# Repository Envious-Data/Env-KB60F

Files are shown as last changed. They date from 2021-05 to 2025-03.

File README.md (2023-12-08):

# Env-KB60F
 Another Custom Mechanical Keyboard... F stands for FOREHEAD!

 Project Name: KB60F
 Nickname: Lil Delirium

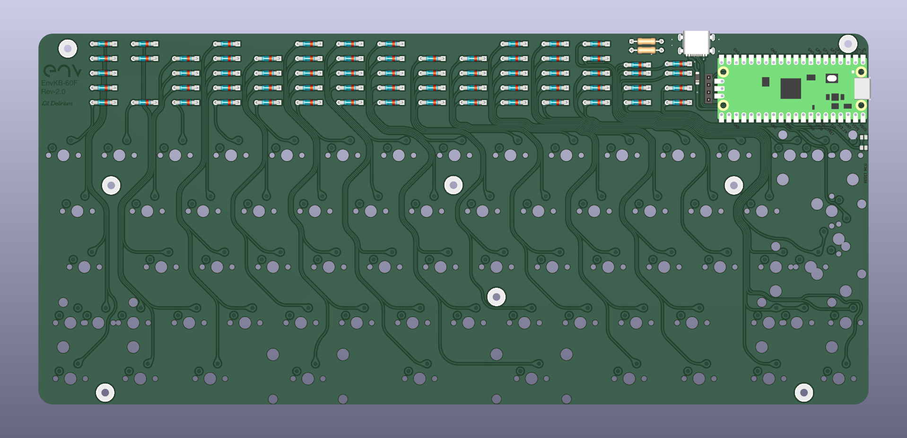
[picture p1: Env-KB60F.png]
PCBShot


### About!
This is a simple-ish 60% design using a Raspberry Pi Pico. Its a standard 60% layout supporting ANSI and ISO.
Optionally if you have your own PCBs made you can use some pogo pins with a 1mm post to connect the TP pads on the underside of a raspberry pi pico, This will allow functionality of the USB type-c port if populated.

there are some spare GPIOs and a space for a header (mainly for a small oled) so feel free to add things if you can, I always enjoy seeing people using my keyboards for things I never thought of or intended.

### DETAILS
This keyboard has been merged into QMK so you can either compile it from the QMK code or download the pre-built firmware
https://github.com/qmk/qmk_firmware/tree/master/keyboards/enviousdesign/60f

https://github.com/Envious-Data/EnvKB-QMK/tree/main/_PREBUILTFIRMWARES

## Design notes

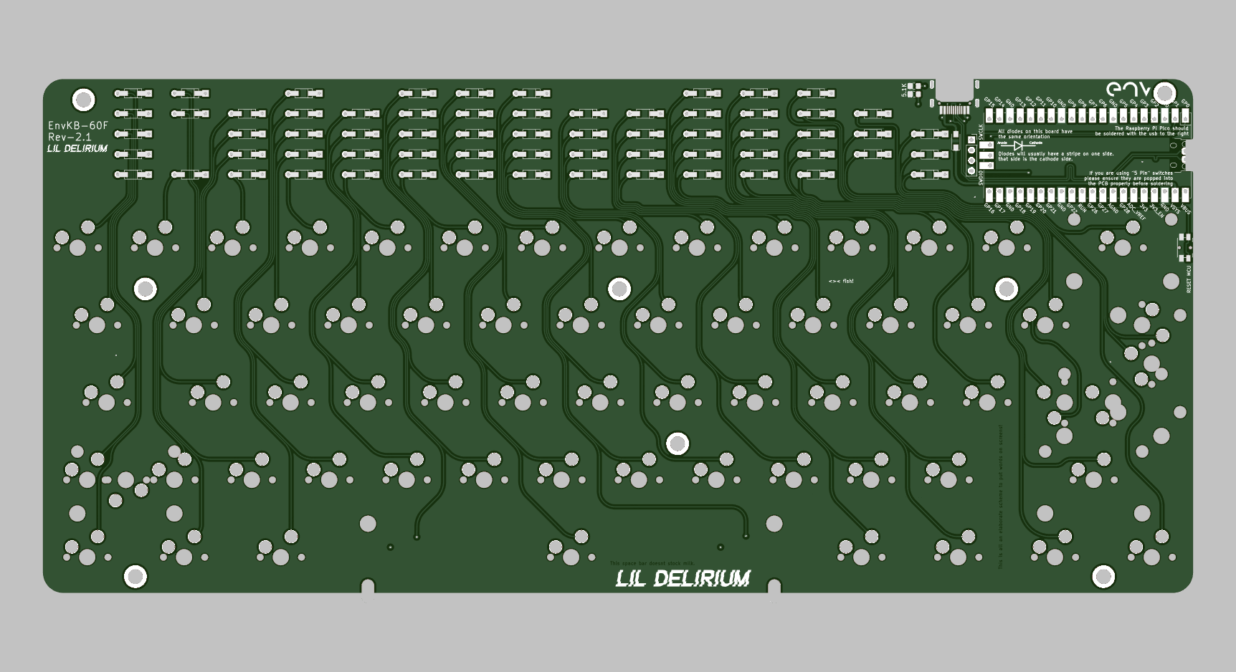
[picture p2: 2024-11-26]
KiCad Files/MainPCB_MX_HS/Env-KB60MXHS.png

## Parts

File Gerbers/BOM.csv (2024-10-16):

Designator | Footprint | Quantity | Value | LCSC Part #
5.1K1, 5.1K2 | 0805 | 2 | 5.1K 0805 Resistor
D_1, D_10, D_11, D_12, D_13, D_14, D_15, D_16, D_17, D_18, D_19, D_2, D_20, D_21, D_22, D_23, D_24, D_25, D_26, D_27, D_28, D_29, D_3, D_30, D_31, D_32, D_33, D_34, D_35, D_36, D_37, D_38, D_39, D_4, D_40, D_41, D_42, D_43, D_44, D_45, D_46, D_47, D_48, D_49, D_5, D_50, D_51, D_52, D_53, D_54, D_55, D_56, D_57, D_58, D_59, D_590, D_591, D_6, D_60, D_61, D_62, D_63, D_7, D_8, D_9 | SOD-123+D_DO-35_SOD27_P7.62mm_Horizontal | 65 | LL4148
D_64 | D_SOD-123 | 1 | 1n5817W
H1, H10, H11, H2, H3, H4, H6, H9 | MountingHole_2.2mm_M2-MODIFIED | 8 | SMTSO2035CTJ
J1 | PinSocket_1x04_P2.54mm_Vertical | 1 | Conn_01x04
K_1, K_10, K_11, K_12, K_13, K_14, K_15, K_16, K_17, K_18, K_19, K_2, K_20, K_21, K_22, K_23, K_24, K_25, K_26, K_27, K_28, K_29, K_3, K_30, K_31, K_32, K_33, K_34, K_35, K_36, K_37, K_38, K_39, K_4, K_40, K_41, K_42, K_43, K_44, K_45, K_46, K_47, K_48, K_49, K_5, K_50, K_51, K_52, K_53, K_54, K_55, K_56, K_57, K_58, K_59, K_6, K_60, K_61, K_62, K_63, K_64, K_65, K_7, K_8, K_9 | MXOnly-1U-Hotswap-Modified | 65 | CPG151101S11
SW1 | Panasonic_EVQPUL_EVQPUC | 1 | EVQPUL
U1 | RPi_Pico_SMD_TH_MODIFIED | 1 | Pico
USB1 | USB_C_TYPE-C-31-M-14 | 1 | TYPE-C-31-M-14 | C319148

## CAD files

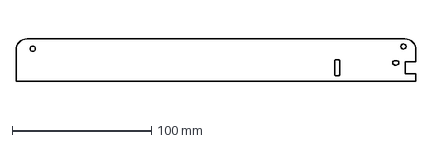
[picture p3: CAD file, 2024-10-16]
KiCad Files/KB60F - Top Cover Acrylic updated.dxf
287.1 x 30.4 mm

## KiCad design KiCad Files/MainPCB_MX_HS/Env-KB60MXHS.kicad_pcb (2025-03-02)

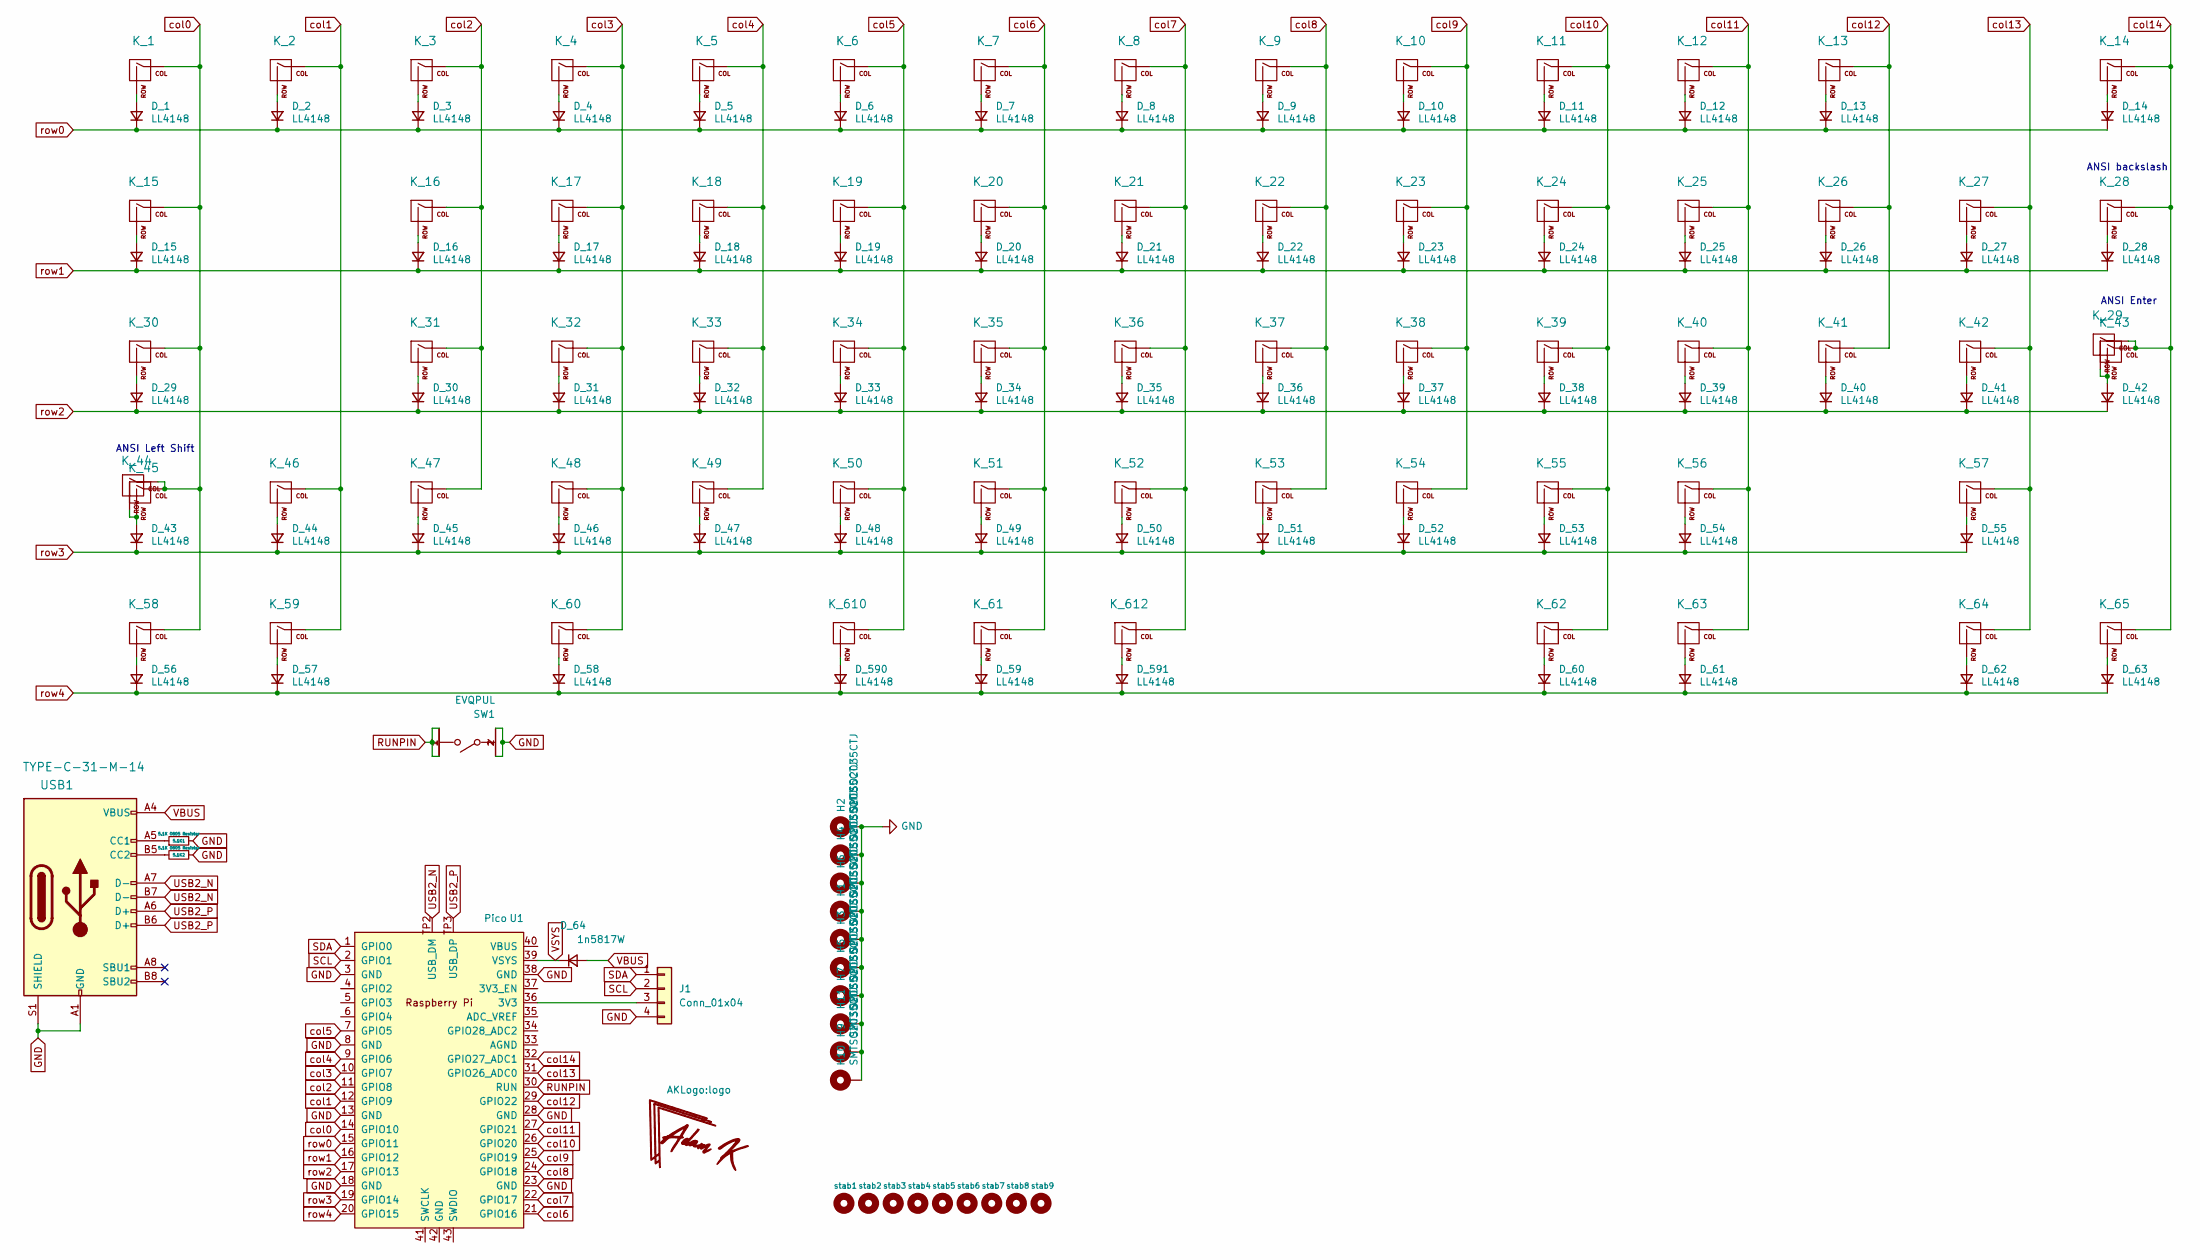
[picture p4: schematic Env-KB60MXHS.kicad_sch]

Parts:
5.1K1, 5.1K2: 5.1K 0805 Resistor; R_0805_2012Metric_Pad1.20x1.40mm_HandSolder
D_1, D_2, D_3, D_4, D_5, D_6, D_7, D_8, D_9, D_10, D_11, D_12, D_13, D_14, D_15, D_16, D_17, D_18, D_19, D_20, D_21, D_22, D_23, D_24, D_25, D_26, D_27, D_28, D_29, D_30, D_31, D_32, D_33, D_34, D_35, D_36, D_37, D_38, D_39, D_40, D_41, D_42, D_43, D_44, D_45, D_46, D_47, D_48, D_49, D_50, D_51, D_52, D_53, D_54, D_55, D_56, D_57, D_58, D_59, D_60, D_61, D_62, D_63, D_590, D_591: LL4148; SOD-123+D_DO-35_SOD27_P7.62mm_Horizontal
D_64: 1n5817W; D_SOD-123
H1, H2, H3, H4, H5, H6, H7, H9, H10, H11: SMTSO2035CTJ; MountingHole_2.2mm_M2-MODIFIED
J1: Conn_01x04; PinSocket_1x04_P2.54mm_Vertical
K_1, K_2, K_3, K_4, K_5, K_6, K_7, K_8, K_9, K_10, K_11, K_12, K_13, K_14, K_15, K_16, K_17, K_18, K_19, K_20, K_21, K_22, K_23, K_24, K_25, K_26, K_27, K_28, K_29, K_30, K_31, K_32, K_33, K_34, K_35, K_36, K_37, K_38, K_39, K_40, K_41, K_42, K_43, K_44, K_45, K_46, K_47, K_48, K_49, K_50, K_51, K_52, K_53, K_54, K_55, K_56, K_57, K_58, K_59, K_60, K_61, K_62, K_63, K_64, K_65, K_610, K_612: CPG151101S11; MXOnly-1U-Hotswap-Modified
SW1: EVQPUL; Panasonic_EVQPUL_EVQPUC
U1: Pico; RPi_Pico_SMD_TH_MODIFIED
USB1: TYPE-C-31-M-14; USB_C_TYPE-C-31-M-14; MPN U262-161N-4BVC11; LCSC C319148
stab1, stab2, stab3, stab4, stab5, stab6, stab7, stab8: MX Stabilizer; Stabilizer_Cherry_MX_2u
stab9: MX Stabilizer; Stabilizer_Cherry_MX_6.25u

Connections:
GND: 5.1K1.2, 5.1K2.1, J1.4, SW1.2, SW1.2', U1.3 (GND), U1.8 (GND), U1.13 (GND), U1.18 (GND), U1.23 (GND), U1.28 (GND), U1.38 (GND), USB1.A1 (GND), USB1.A12 (GND), USB1.B1 (GND), USB1.B12 (GND), USB1.S1 (SHIELD)
unnamed: D_1.2 (A), K_1.2 (ROW)
unnamed: D_2.2 (A), K_2.2 (ROW)
unnamed: D_3.2 (A), K_3.2 (ROW)
unnamed: D_4.2 (A), K_4.2 (ROW)
unnamed: D_5.2 (A), K_5.2 (ROW)
unnamed: D_6.2 (A), K_6.2 (ROW)
unnamed: D_7.2 (A), K_7.2 (ROW)
unnamed: D_8.2 (A), K_8.2 (ROW)
unnamed: D_9.2 (A), K_9.2 (ROW)
unnamed: D_10.2 (A), K_10.2 (ROW)
unnamed: D_11.2 (A), K_11.2 (ROW)
unnamed: D_12.2 (A), K_12.2 (ROW)
unnamed: D_13.2 (A), K_13.2 (ROW)
unnamed: D_14.2 (A), K_14.2 (ROW)
unnamed: D_15.2 (A), K_15.2 (ROW)
unnamed: D_16.2 (A), K_16.2 (ROW)
unnamed: D_17.2 (A), K_17.2 (ROW)
unnamed: D_18.2 (A), K_18.2 (ROW)
unnamed: D_19.2 (A), K_19.2 (ROW)
unnamed: D_20.2 (A), K_20.2 (ROW)
unnamed: D_21.2 (A), K_21.2 (ROW)
unnamed: D_22.2 (A), K_22.2 (ROW)
unnamed: D_23.2 (A), K_23.2 (ROW)
unnamed: D_24.2 (A), K_24.2 (ROW)
unnamed: D_25.2 (A), K_25.2 (ROW)
unnamed: D_26.2 (A), K_26.2 (ROW)
unnamed: D_27.2 (A), K_27.2 (ROW)
unnamed: D_28.2 (A), K_28.2 (ROW)
unnamed: D_29.2 (A), K_30.2 (ROW)
unnamed: D_30.2 (A), K_31.2 (ROW)
unnamed: D_31.2 (A), K_32.2 (ROW)
unnamed: D_32.2 (A), K_33.2 (ROW)
unnamed: D_33.2 (A), K_34.2 (ROW)
unnamed: D_34.2 (A), K_35.2 (ROW)
unnamed: D_35.2 (A), K_36.2 (ROW)
unnamed: D_36.2 (A), K_37.2 (ROW)
unnamed: D_37.2 (A), K_38.2 (ROW)
unnamed: D_38.2 (A), K_39.2 (ROW)
unnamed: D_39.2 (A), K_40.2 (ROW)
unnamed: D_40.2 (A), K_41.2 (ROW)
unnamed: D_41.2 (A), K_42.2 (ROW)
unnamed: D_42.2 (A), K_29.2 (ROW), K_43.2 (ROW)
unnamed: D_43.2 (A), K_44.2 (ROW), K_45.2 (ROW)
unnamed: D_44.2 (A), K_46.2 (ROW)
unnamed: D_45.2 (A), K_47.2 (ROW)
unnamed: D_46.2 (A), K_48.2 (ROW)
unnamed: D_47.2 (A), K_49.2 (ROW)
unnamed: D_48.2 (A), K_50.2 (ROW)
unnamed: D_49.2 (A), K_51.2 (ROW)
unnamed: D_50.2 (A), K_52.2 (ROW)
unnamed: D_51.2 (A), K_53.2 (ROW)
unnamed: D_52.2 (A), K_54.2 (ROW)
unnamed: D_53.2 (A), K_55.2 (ROW)
unnamed: D_54.2 (A), K_56.2 (ROW)
unnamed: D_55.2 (A), K_57.2 (ROW)
unnamed: D_56.2 (A), K_58.2 (ROW)
unnamed: D_57.2 (A), K_59.2 (ROW)
unnamed: D_58.2 (A), K_60.2 (ROW)
unnamed: D_59.2 (A), K_61.2 (ROW)
unnamed: D_60.2 (A), K_62.2 (ROW)
unnamed: D_61.2 (A), K_63.2 (ROW)
unnamed: D_62.2 (A), K_64.2 (ROW)
unnamed: D_63.2 (A), K_65.2 (ROW)
unnamed: D_590.2 (A), K_610.2 (ROW)
unnamed: D_591.2 (A), K_612.2 (ROW)
unnamed: H1.1, H2.1, H3.1, H4.1, H5.1, H6.1, H7.1, H9.1, H10.1, H11.1
unnamed: J1.3, U1.36 (3V3)
unnamed: 5.1K1.1, USB1.A5 (CC1)
unnamed: 5.1K2.2, USB1.B5 (CC2)
RUNPIN: SW1.1, SW1.1', U1.30 (RUN)
SCL: J1.2, U1.2 (GPIO1)
SDA: J1.1, U1.1 (GPIO0)
USB2_N: U1.TP2 (USB_DM), USB1.A7 (D-), USB1.B7 (D-)
USB2_P: U1.TP3 (USB_DP), USB1.A6 (D+), USB1.B6 (D+)
VBUS: D_64.2 (A), USB1.A4 (VBUS), USB1.A9 (VBUS), USB1.B4 (VBUS), USB1.B9 (VBUS)
VSYS: D_64.1 (K), U1.39 (VSYS)
col0: K_1.1 (COL), K_15.1 (COL), K_30.1 (COL), K_44.1 (COL), K_45.1 (COL), K_58.1 (COL), U1.14 (GPIO10)
col1: K_2.1 (COL), K_46.1 (COL), K_59.1 (COL), U1.12 (GPIO9)
col2: K_3.1 (COL), K_16.1 (COL), K_31.1 (COL), K_47.1 (COL), U1.11 (GPIO8)
col3: K_4.1 (COL), K_17.1 (COL), K_32.1 (COL), K_48.1 (COL), K_60.1 (COL), U1.10 (GPIO7)
col4: K_5.1 (COL), K_18.1 (COL), K_33.1 (COL), K_49.1 (COL), U1.9 (GPIO6)
col5: K_6.1 (COL), K_19.1 (COL), K_34.1 (COL), K_50.1 (COL), K_610.1 (COL), U1.7 (GPIO5)
col6: K_7.1 (COL), K_20.1 (COL), K_35.1 (COL), K_51.1 (COL), K_61.1 (COL), U1.21 (GPIO16)
col7: K_8.1 (COL), K_21.1 (COL), K_36.1 (COL), K_52.1 (COL), K_612.1 (COL), U1.22 (GPIO17)
col8: K_9.1 (COL), K_22.1 (COL), K_37.1 (COL), K_53.1 (COL), U1.24 (GPIO18)
col9: K_10.1 (COL), K_23.1 (COL), K_38.1 (COL), K_54.1 (COL), U1.25 (GPIO19)
col10: K_11.1 (COL), K_24.1 (COL), K_39.1 (COL), K_55.1 (COL), K_62.1 (COL), U1.26 (GPIO20)
col11: K_12.1 (COL), K_25.1 (COL), K_40.1 (COL), K_56.1 (COL), K_63.1 (COL), U1.27 (GPIO21)
col12: K_13.1 (COL), K_26.1 (COL), K_41.1 (COL), U1.29 (GPIO22)
col13: K_27.1 (COL), K_42.1 (COL), K_57.1 (COL), K_64.1 (COL), U1.31 (GPIO26_ADC0)
col14: K_14.1 (COL), K_28.1 (COL), K_29.1 (COL), K_43.1 (COL), K_65.1 (COL), U1.32 (GPIO27_ADC1)
row0: D_1.1 (K), D_2.1 (K), D_3.1 (K), D_4.1 (K), D_5.1 (K), D_6.1 (K), D_7.1 (K), D_8.1 (K), D_9.1 (K), D_10.1 (K), D_11.1 (K), D_12.1 (K), D_13.1 (K), D_14.1 (K), U1.15 (GPIO11)
row1: D_15.1 (K), D_16.1 (K), D_17.1 (K), D_18.1 (K), D_19.1 (K), D_20.1 (K), D_21.1 (K), D_22.1 (K), D_23.1 (K), D_24.1 (K), D_25.1 (K), D_26.1 (K), D_27.1 (K), D_28.1 (K), U1.16 (GPIO12)
row2: D_29.1 (K), D_30.1 (K), D_31.1 (K), D_32.1 (K), D_33.1 (K), D_34.1 (K), D_35.1 (K), D_36.1 (K), D_37.1 (K), D_38.1 (K), D_39.1 (K), D_40.1 (K), D_41.1 (K), D_42.1 (K), U1.17 (GPIO13)
row3: D_43.1 (K), D_44.1 (K), D_45.1 (K), D_46.1 (K), D_47.1 (K), D_48.1 (K), D_49.1 (K), D_50.1 (K), D_51.1 (K), D_52.1 (K), D_53.1 (K), D_54.1 (K), D_55.1 (K), U1.19 (GPIO14)
row4: D_56.1 (K), D_57.1 (K), D_58.1 (K), D_59.1 (K), D_60.1 (K), D_61.1 (K), D_62.1 (K), D_63.1 (K), D_590.1 (K), D_591.1 (K), U1.20 (GPIO15)

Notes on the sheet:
ANSI Left Shift
ANSI backslash
ANSI Enter

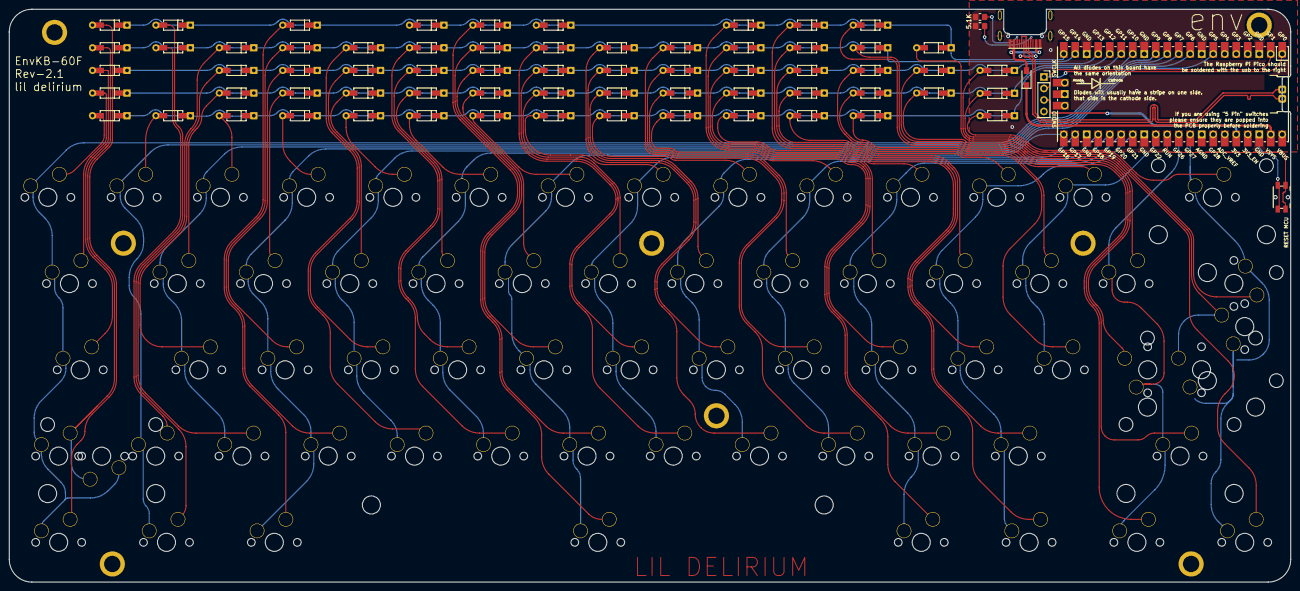
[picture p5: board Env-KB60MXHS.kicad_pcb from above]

Board: 2 copper layers, 283.0 x 126.5 mm, 151 parts (0 on the bottom side), 94 nets.

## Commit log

2021-04-23 Added Files n whatnot
    [Env-KB60F.kicad_pcb, Env-KB60F.sch]
2021-04-23 Aligned diodes as preferred
    [Env-KB60F.kicad_pcb]
2021-04-23 Diodes were wrong direction
    [Env-KB60F.kicad_pcb, Env-KB60F.sch]
2021-04-23 Added More traces n stuff
    [Env-KB60F.kicad_pcb]
2021-04-23 General Re-doing of stuff
    [Env-KB60F.kicad_pcb, Env-KB60F.sch]
2021-04-24 Added some mount holes n stuff
    [Env-KB60F.kicad_pcb, Env-KB60F.sch]
2021-04-24 Spotted a lil derp and fixed it
    [Env-KB60F.kicad_pcb]
2021-04-24 Added some stuff
    Added a Button for reset and also a bunch of silkscreen instructions for building the keyboard aswell as a QR Code URL that brings you to this Repository.
    [Env-KB60F.kicad_pcb, Env-KB60F.sch, Panasonic_-_EVQ-P7A01P.step]
2021-04-24 Changed QR Code
    meh its a easter egg now.
    [Env-KB60F.kicad_pcb]
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2021-05-06 Added ANSI Left Shift, Enter and Backslash
    [Env-KB60F.kicad_pcb, Env-KB60F.sch]
2021-05-11 Designed New Plate, adjusted mount holes and fixed trace issues.
    [Env-KB60F.kicad_pcb, Env-KB60F.sch]
2021-05-16 Added a optional top USB port based on feedback
    [Env-KB60F.kicad_pcb, Env-KB60F.sch]
2021-05-16 Added missing graphic
    [Env-KB60F.kicad_pcb]
2021-05-25 Cleaned up Repo - Adjusted traces and mount hole locations + generated blank back PCB
    [Env-KB60F-BACK.kicad_pcb, Env-KB60F-BACK.sch, Env-KB60F.kicad_pcb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]
2021-05-25 Moved MCU lower to allow for mount hole to fit properly, Generated Gerber and bottom plate Gerber
    [Env-KB60F.kicad_pcb, Env-KB60F.sch, _bom.csv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]
2021-05-27 Corrected silkscreen, Generated updated Gerbers
    [Env-KB60F-B_Cu.gbl, Env-KB60F-B_Mask.gbs, Env-KB60F-B_Paste.gbp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]
2021-05-27 somehow missed a screwup on the silkscreen
    [Env-KB60F-B_Cu.gbl, Env-KB60F-B_Mask.gbs, Env-KB60F-B_Paste.gbp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]
2021-05-31 General Checkover and adjustments, Generated Gerbers for JLCPCB
    [Env-KB60F-B_Cu.gbl, Env-KB60F-B_Mask.gbs, Env-KB60F-B_Paste.gbp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]
2021-06-11 Tweaked USB P/N Traces
    [Env-KB60F.kicad_pcb]
2021-06-15 Generated DXF for CNC or Laser cut.
    [EKB60 - Acrylic Laser Cut.dxf, Env-KB60F.kicad_pcb, Env-KB60F.sch]
2021-08-01 Made Laser Cut stuff for top plate
    [60F-TopPlate.dxf, EKB60 - Acrylic Laser Cut.dxf, Env-KB60F.csv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]
2021-08-04 updated laser cut dxf
    [KB60F-TopPlate.dxf]
2021-08-20 moved a CC resistor out of the way of some silkscreen.
    [Env-KB60F.kicad_pcb]
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2021-08-30 fixed backplate's ground fill and added a center logo on the rear of it.
    [Env-KB60F.kicad_pcb]
2021-08-30 reorganize folder/files, added triple spacebar
    [Env-KB60F.kicad_pcb, Env-KB60F.sch, Panasonic_-_EVQ-P7A01P.step]
2021-08-30 started work on RP2040 version.
    [EKB60 - Acrylic Laser Cut.dxf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]
2021-08-30 finished up RP2040 version, need to fill the blank space.
    [Env-KB60F.kicad_pcb]
2021-08-30 finished up RP2040 version some more, added debug header and spare GPIO header.
    [Env-KB60F.kicad_pcb, Env-KB60F.sch]
2021-08-30 Corrected mount hole placement on all PCBs and updated the switch plate to fit triple spacebar split.
    [Env-KB60F.kicad_pcb, Env-KB60F.sch]
2021-08-30 updated git ignore to allow BOM/CPL and updated readme.
    [Env-KB60F.csv, Env-KB60F.kicad_pcb, Env-KB60F_bom_jlc.csv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]
2021-09-04 tested some logos and placements to fill empty space, might relocate the MCU setup a bit.
    [Env-KB60F.kicad_pcb]
2021-09-20 started work on hotswap version
    [EKB60 - Acrylic Laser Cut.dxf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]
2021-09-20 finished up hotswap version traces
    [Env-KB60FHS-B_Cu.gbl, Env-KB60FHS-B_Mask.gbs, Env-KB60FHS-B_Paste.gbp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]
2022-05-06 polished up design and removed other versions for now, will re-do hotswap version.
    [EKB60 - Acrylic Laser Cut.dxf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]
2022-05-06 forgot to save schematic changes
    [Env-KB60F.kicad_sch]
2022-05-06 overall cleanup, will need to fix stuff probably.
    [EKB60 - Acrylic Laser Cut.dxf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]
2022-05-06 some more updates n stuff
    [Env-KB60F.sch]
2022-05-06 more cleanup and sorting
    [Env-KB60F-B_Cu.gbl, Env-KB60F-B_Mask.gbs, Env-KB60F-B_Paste.gbp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]
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2022-05-18 small tweaks regarding silkscreen
    [Env-KB60F.kicad_sch]
2022-05-18 Created Choc V2 Version
    [Env-KB60F.kicad_sch]
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2022-05-20 renamed choc V2 version project
    [Env-KB60C2.kicad_sch, Env-KB60F.kicad_sch]
2022-05-30 swapped power input for MCU to VSYS instead of VBUS
    [Env-KB60F.kicad_sch]
2022-06-16 some various corrections to the USB DP/DM traces
    [Env-KB60C2.kicad_sch, Env-KB60F.kicad_sch]
2022-06-24 swapped mount holes
    [Env-KB60C2.kicad_sch]
2022-06-26 redid front traces to be less mechanically damage prone
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2022-07-25 moved mount hole, redid switchplate and backplate
    [60FBackplate.kicad_pcb, 60FBackplate.kicad_sch, 60FSwitchPlate-MX.kicad_pcb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]
2022-10-06 made some temporary adjustments to test SMD Nuts
    [Env-KB60F.kicad_sch]
2022-10-07 some checking over for future
    [60FSwitchPlate-MX.kicad_pcb]
2022-10-12 added I2C header and protection diode to MX version
    [Env-KB60F.kicad_sch]
2022-10-12 made hotswap version based on MX variant
    [Env-KB60MXHS.kicad_sch]
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2022-12-01 modified mount holes for future test
    [Env-KB60MXHS.kicad_sch]
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2023-02-02 added split backspace and right shift
    backspace is 1u+1u and right shift is 1.75u + 1u.
    [Env-KB60F.kicad_sch]
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2023-05-03 corrected issue on MX variant, spacebar was not aligned correctly
    [60FSwitchPlate-MX.kicad_pcb]
2023-09-27 updated MX version a tiny bit, might order and do a tiny kit run.
    [Env-KB60F.kicad_sch]
2023-09-29 various design work toward producing and making a case
    [Env-KB60F.kicad_sch, bom.csv, designators.csv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]
2023-12-08 Made experiment version and some experimental diode footprint.
    [Env-KB60F.kicad_sch, Env-KB60F_bom_jlc.csv, bom.csv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]
2023-12-08 got rid of experimental version as it served its purpose.
    [Env-KB60F.kicad_sch, Env-KB60F_bom_jlc.csv, bom.csv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]
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2023-12-08 Corrected mount hole parity between mainPCB MX and Backplate.
    [60F top cover.dxf, 60FBackplate.kicad_pcb, Env-KB60F_bom_jlc.csv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]
2023-12-08 got rid of choc versions as they are non viable sadly.
    [Env-KB60C2.kicad_sch, SwitchPlate_ChocV2.kicad_pcb, SwitchPlate_ChocV2.kicad_sch]
2023-12-08 fixed parity between main MX PCB and switch plate.
    [60FSwitchPlate-MX.kicad_pcb]
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2023-12-08 re-made a couple files I forgot to include.
    [KB60F - Backplate.dxf, KB60F - Top Cover Acrylic.dxf, KB60F switchplate.dxf]
2023-12-11 corrected font.
    [60FBackplate.kicad_pcb]
2024-01-27 updated hotswap version to have SMT compatible diode footprints
    [Env-KB60MXHS.kicad_sch, bom.csv, designators.csv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]
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2024-08-27 fixed issues with alignment
    [60FSwitchPlate-MX.kicad_pcb, 60FSwitchPlate-MX.kicad_sch, BOM.csv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]
2024-09-19 fixed alignment issues, generated gerbers, fixed silkscreen issues, fixed footprints, generated gerbers
    [60FBackplate.kicad_pcb, 60FBackplate.kicad_sch, 60FSwitchPlate-MX.kicad_pcb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]
2024-09-19 updated BOM,CPL to include missing parts needed, updated the values
    [BOM.csv, Env-KB60MXHS.kicad_pcb, Env-KB60MXHS.kicad_sch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]
2024-10-16 Corrected Several issues pointed out by Dasky (tyvm), reduced top cover size to not conflict with the plate, swapped oled header power for correct voltage, extended several pads to make it easier to 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
    [BOM.csv, Env-KB60MXHS.kicad_pcb, Env-KB60MXHS.kicad_sch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]
2024-10-16 fixed a missing ground connection.
    [Env-KB60MXHS.kicad_pcb]
2024-10-17 changed TP pad cutout for USB to be on the edge of the board for easier soldering, updated silkscreen note.
    [Env-KB60MXHS.kicad_pcb]
2024-10-17 forgot to save and commit changes on the PCB file.
    [Env-KB60MXHS.kicad_pcb]
2024-10-18 fixed iso enter stabiliser position, validated position of ansi enter, ansi backslash, iso enter, iso right bracket, iso hash key.
    [Env-KB60MXHS.kicad_pcb]
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2025-03-02 removed ground fill to see how it would look with transparent soldermask
    [Env-KB60MXHS.kicad_pcb]
